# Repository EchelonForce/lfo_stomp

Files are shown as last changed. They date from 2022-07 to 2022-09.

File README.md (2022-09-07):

# Eurorack LFO Stomp

This is a PCB for a eurorack LFO based on the STOMPLFO chip from Electric Druid.

Full writeup here: https://www.robotdialogs.com/2022/09/eurorack-lfo-module-stomp-lfo.html

This work is licensed under a Creative Commons Attribution-NonCommercial-ShareAlike 4.0 International License. https://creativecommons.org/licenses/by-nc-sa/4.0/

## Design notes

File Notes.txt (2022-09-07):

Stomp-LFO Design Notes

Data sheet has a simple filter to smooth out the PDM output to make the actual LFO output. That seems okay on the breadboard. 

Initially on the breadboard I had the 7805 regulator backwards so it got super hot and let somekind of bad voltage through to the STOMPLFO, so that chip misbehaved after I corrected the regulator. It was drawing 80mA at 5V and I couldn't figure out why and the data sheet doesn't list a typical current. Since it was sort of working I started measuring the output, but was only getting 0 to ~2.5V at the output PDM pin. At this point I decided to try another chip and the new one behaved as expected, so I just fried that first chip and then had to troubleshoot to figure that out.

Breadboard doesn't have an LED output, but I like having one for LFOs, so add that in v1 PCB.
There's another Op-amp available on the output buffer. Maybe make an inverted output if there's room on the panel for another jack.

https://tinyurl.com/252rokoo

v1 pcb issues
- Filter from the data sheet that I used with the output buffer/amp's R4 created a voltage divider that makes the output 0-5V instead of 0-10V. 
    - Using (R8+R5=430k and R7=30k) cranks it up to 0-10V as desired. see https://tinyurl.com/2bfdjrho
- R10 could/should be two 1k's instead of a 2k to reduce number of components.

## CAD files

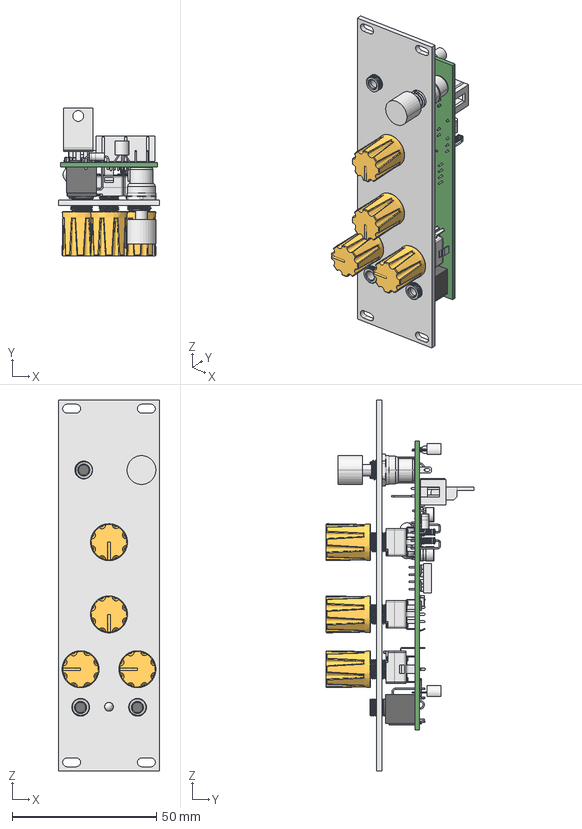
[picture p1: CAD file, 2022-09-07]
front_panel_v1/lfo_stomp_front_panel_v1.1.FCStd
35.0 x 51.3 x 128.5 mm
lfo_stomp_v1 PCB

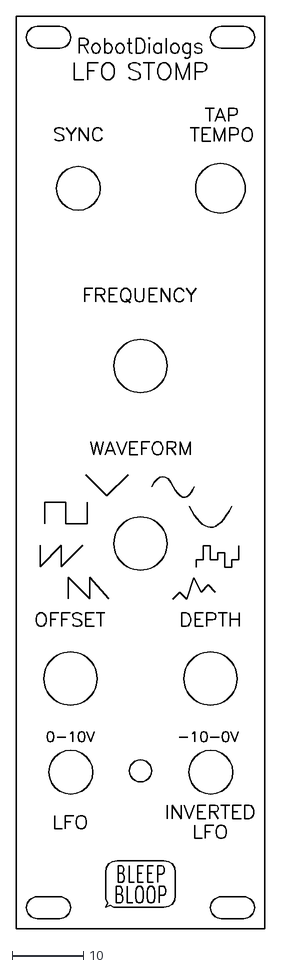
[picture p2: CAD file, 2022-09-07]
front_panel_v1/lfo_stomp_front_panel_v1.1_engraving.dxf
35.0 x 128.5

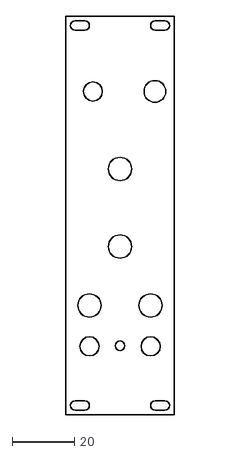
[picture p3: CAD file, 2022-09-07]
front_panel_v1/lfo_stomp_front_panel_v1_no_engraving.dxf
35.0 x 128.5

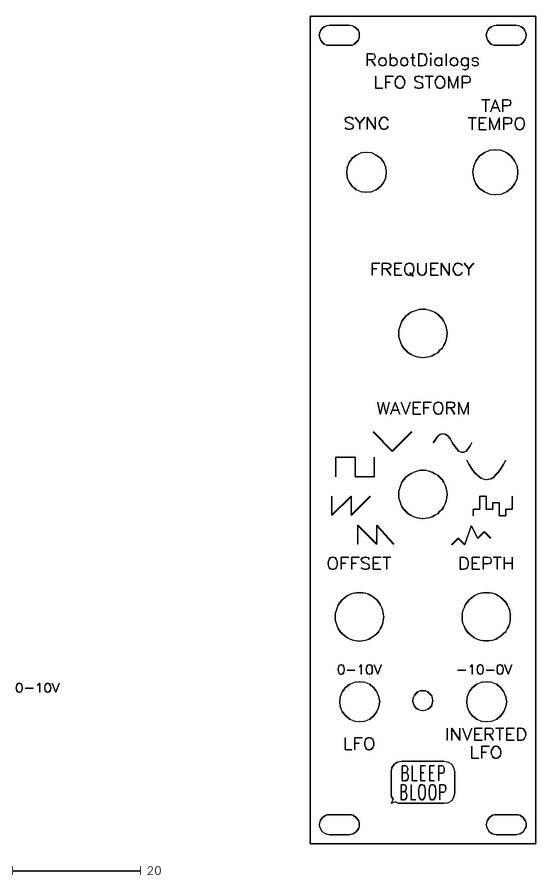
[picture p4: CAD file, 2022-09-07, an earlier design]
front_panel_v1/lfo_stomp_front_panel_v1_engraving.dxf
80.6 x 128.5

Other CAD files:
front_panel_v1/lfo_stomp_front_panel_v1.FCStd

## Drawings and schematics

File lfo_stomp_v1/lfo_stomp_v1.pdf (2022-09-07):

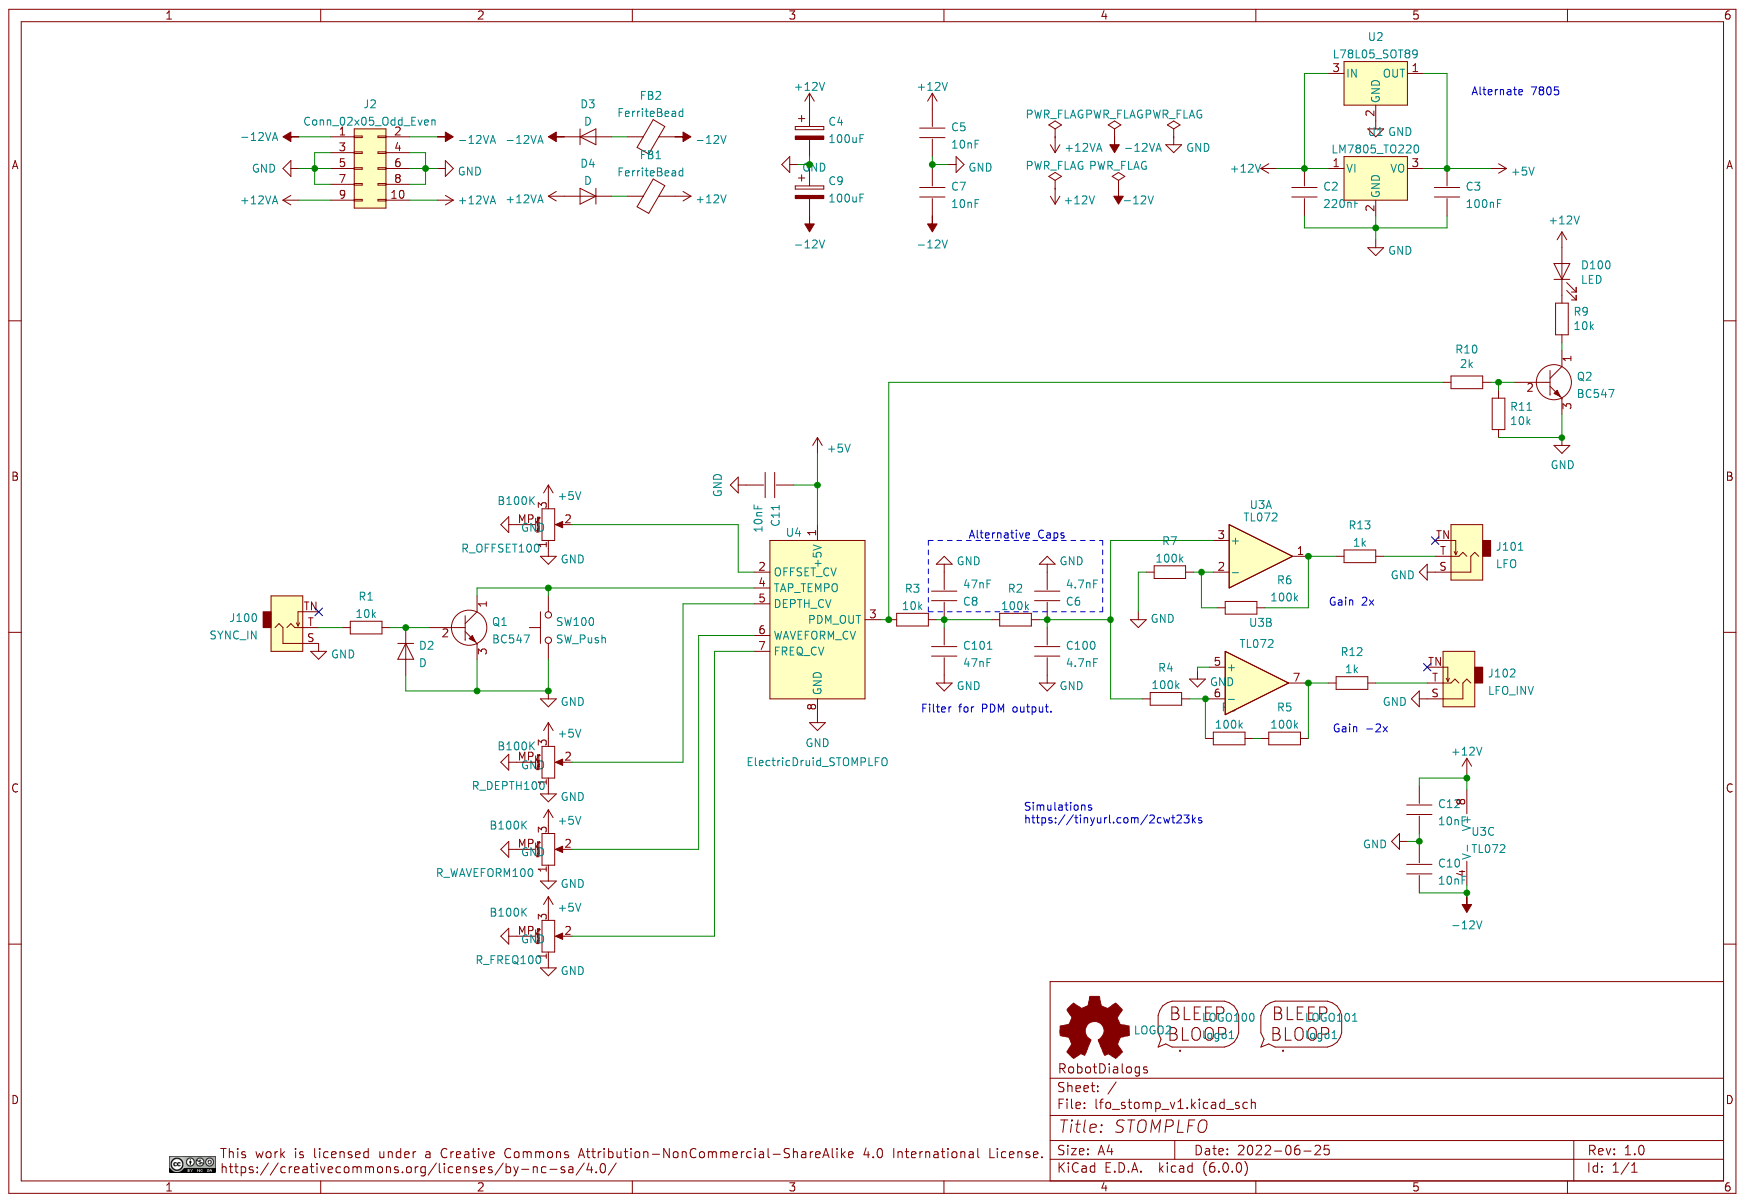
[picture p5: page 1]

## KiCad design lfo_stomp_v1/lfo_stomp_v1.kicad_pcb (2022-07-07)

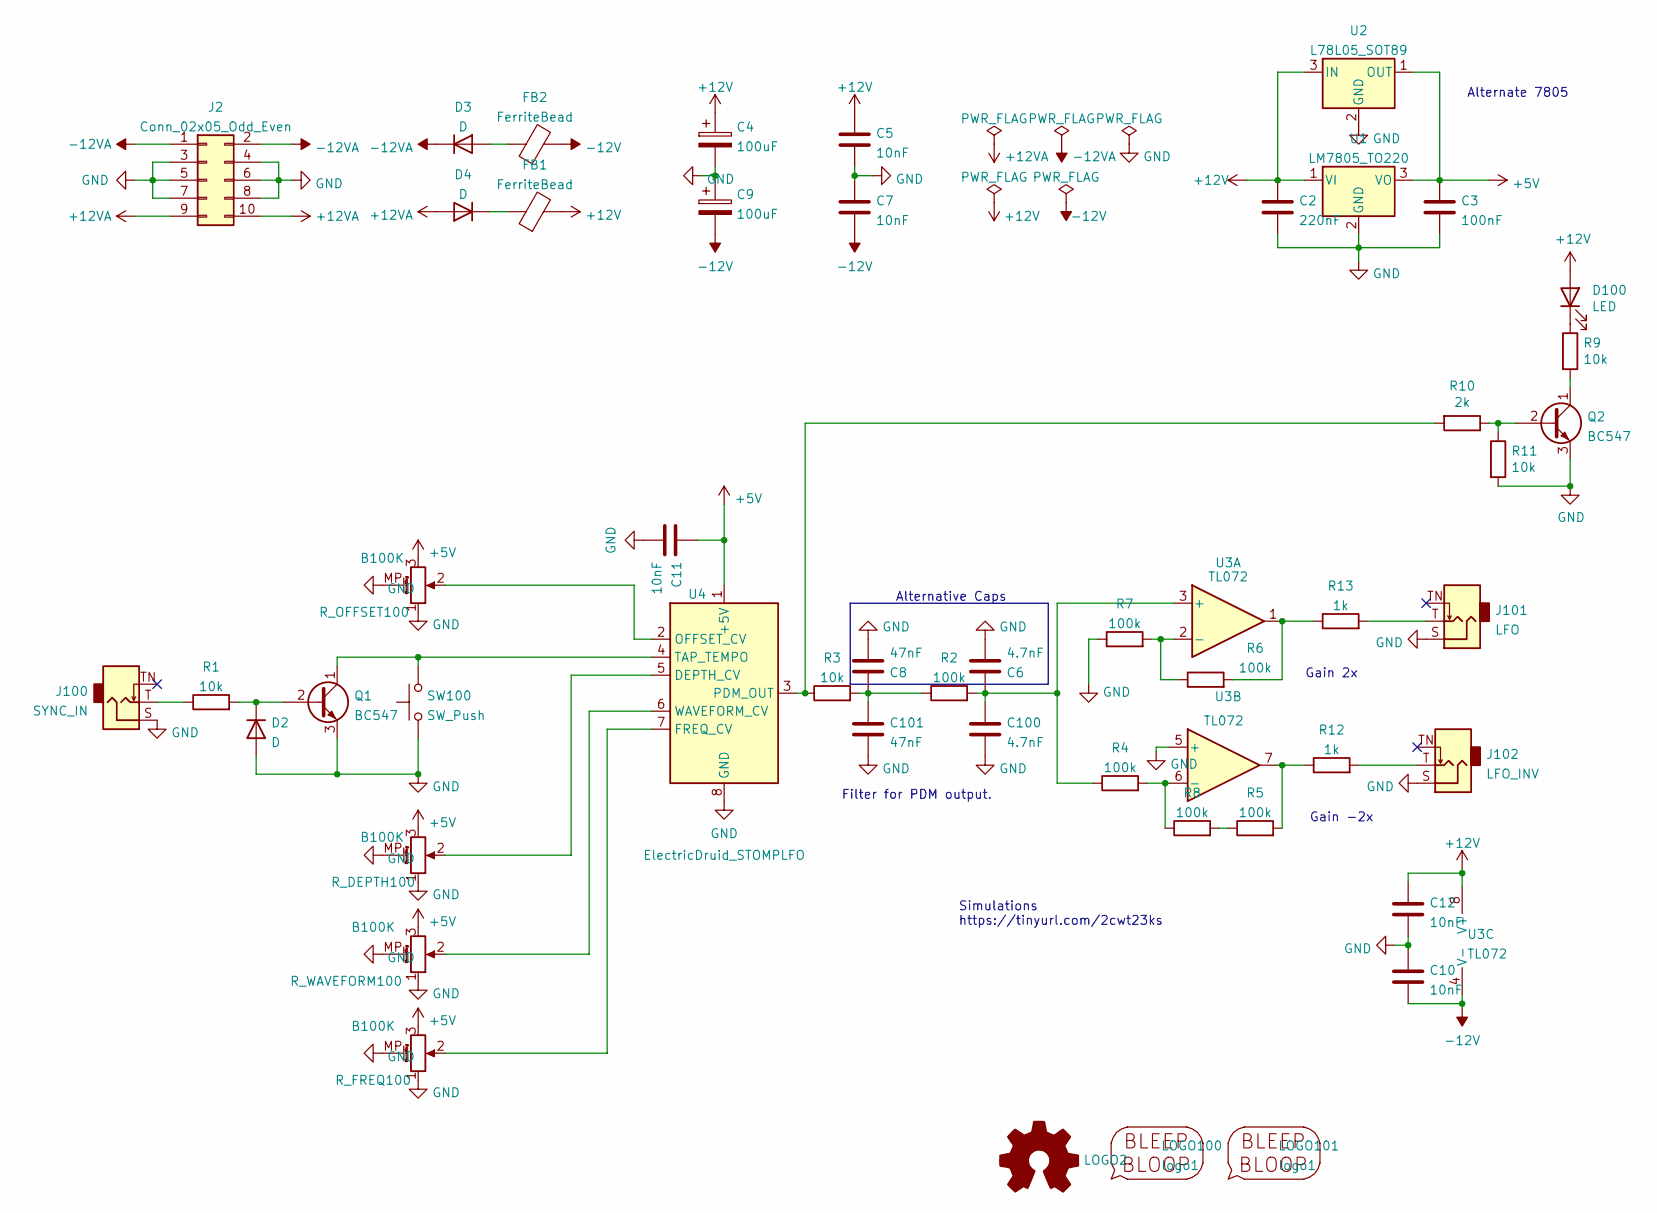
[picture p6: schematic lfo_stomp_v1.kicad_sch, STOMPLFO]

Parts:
C2: 220nF; C_1206_3216Metric_Pad1.33x1.80mm_HandSolder
C3: 100nF; C_1206_3216Metric_Pad1.33x1.80mm_HandSolder
C4, C9: 100uF; CP_Radial_D5.0mm_P2.50mm
C5, C7, C10, C11, C12: 10nF; C_1206_3216Metric_Pad1.33x1.80mm_HandSolder
C6: 4.7nF; C_1206_3216Metric_Pad1.33x1.80mm_HandSolder
C8: 47nF; C_1206_3216Metric_Pad1.33x1.80mm_HandSolder
C100: 4.7nF; C_Disc_D5.1mm_W3.2mm_P5.00mm
C101: 47nF; C_Disc_D5.1mm_W3.2mm_P5.00mm
D2, D3, D4: D; D_A-405_P7.62mm_Horizontal
D100: LED; LED_D3.0mm
FB1, FB2: FerriteBead; L_Axial_L5.3mm_D2.2mm_P2.54mm_Vertical_Vishay_IM-1
J2: Conn_02x05_Odd_Even; IDC-Header_2x05_P2.54mm_Vertical
J100: SYNC_IN; Jack_3.5mm_MJ-355W_and_PJ398SM_Vertical
J101: LFO; Jack_3.5mm_MJ-355W_and_PJ398SM_Vertical
J102: LFO_INV; Jack_3.5mm_MJ-355W_and_PJ398SM_Vertical
LOGO2: Logo_Open_Hardware_Small; OSHW-Symbol_6.7x6mm_SilkScreen
LOGO100: logo1; Logo1
LOGO101: logo1; Logo2
Q1, Q2: BC547; TO-92_Inline_Wide
R1, R3, R9, R11: 10k; R_1206_3216Metric_Pad1.30x1.75mm_HandSolder
R2, R4, R5, R6, R7, R8: 100k; R_1206_3216Metric_Pad1.30x1.75mm_HandSolder
R10: 2k; R_1206_3216Metric_Pad1.30x1.75mm_HandSolder
R12, R13: 1k; R_1206_3216Metric_Pad1.30x1.75mm_HandSolder
R_DEPTH100: B100K; Potentiometer_Alpha_RD901F-40-00D_Single_Vertical_w_3d
R_FREQ100: B100K; Potentiometer_Alpha_RD901F-40-00D_Single_Vertical_w_3d
R_OFFSET100: B100K; Potentiometer_Alpha_RD901F-40-00D_Single_Vertical_w_3d
R_WAVEFORM100: B100K; Potentiometer_Alpha_RD901F-40-00D_Single_Vertical_w_3d
SW100: SW_Push; SW_PS1024ALRED
U1: LM7805_TO220; TO-220-3_Vertical
U2: L78L05_SOT89; SOT-89-3
U3: TL072; DIP-8_W7.62mm_Socket_LongPads
U4: ElectricDruid_STOMPLFO; DIP-8_W7.62mm_Socket_LongPads

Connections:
+5V: C3.1, C11.1, R_DEPTH100.3, R_FREQ100.3, R_OFFSET100.3, R_WAVEFORM100.3, U1.3 (VO), U2.1 (OUT), U4.1 (+5V)
+12V: C2.1, C4.1, C5.1, C12.1, D100.2 (A), FB1.2, U1.1 (VI), U2.3 (IN), U3.8 (V+)
+12VA: D4.2 (A), J2.9, J2.10
-12V: C7.2, C9.2, C10.2, FB2.2, U3.4 (V-)
-12VA: D3.1 (K), J2.1, J2.2
GND: C2.2, C3.2, C4.2, C5.2, C6.2, C7.1, C8.2, C9.1, C10.1, C11.2, C12.2, C100.2, C101.2, D2.2 (A), J2.3, J2.4, J2.5, J2.6, J2.7, J2.8, J100.S, J101.S, J102.S, Q1.3 (E), Q2.3 (E), R7.1, R11.2, R_DEPTH100.1, R_DEPTH100.MP (MountPin), R_FREQ100.1, R_FREQ100.MP (MountPin), R_OFFSET100.1, R_OFFSET100.MP (MountPin), R_WAVEFORM100.1, R_WAVEFORM100.MP (MountPin), SW100.1, U1.2 (GND), U2.2 (GND), U3.5 (+), U4.8 (GND)
unnamed: C6.1, C100.1, R2.2, R4.1, U3.3 (+)
unnamed: C8.1, C101.1, R2.1, R3.2
unnamed: D2.1 (K), Q1.2 (B), R1.2
unnamed: D3.2 (A), FB2.1
unnamed: D4.1 (K), FB1.1
unnamed: D100.1 (K), R9.1
unnamed: J100.T, R1.1
unnamed: J101.T, R13.2
unnamed: J102.T, R12.2
unnamed: Q1.1 (C), SW100.2, U4.4 (TAP_TEMPO)
unnamed: R3.1, R10.2, U4.3 (PDM_OUT)
unnamed: R4.2, R8.1, U3.6 (-)
unnamed: R5.1, R8.2
unnamed: R6.1, R7.2, U3.2 (-)
unnamed: Q2.1 (C), R9.2
unnamed: Q2.2 (B), R10.1, R11.1
unnamed: R5.2, R12.1, U3.7
unnamed: R6.2, R13.1, U3.1
unnamed: R_DEPTH100.2, U4.5 (DEPTH_CV)
unnamed: R_FREQ100.2, U4.7 (FREQ_CV)
unnamed: R_OFFSET100.2, U4.2 (OFFSET_CV)
unnamed: R_WAVEFORM100.2, U4.6 (WAVEFORM_CV)

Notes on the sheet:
Filter for PDM output.
Gain 2x
Gain -2x
Simulations https://tinyurl.com/2cwt23ks
Alternate 7805
Alternative Caps

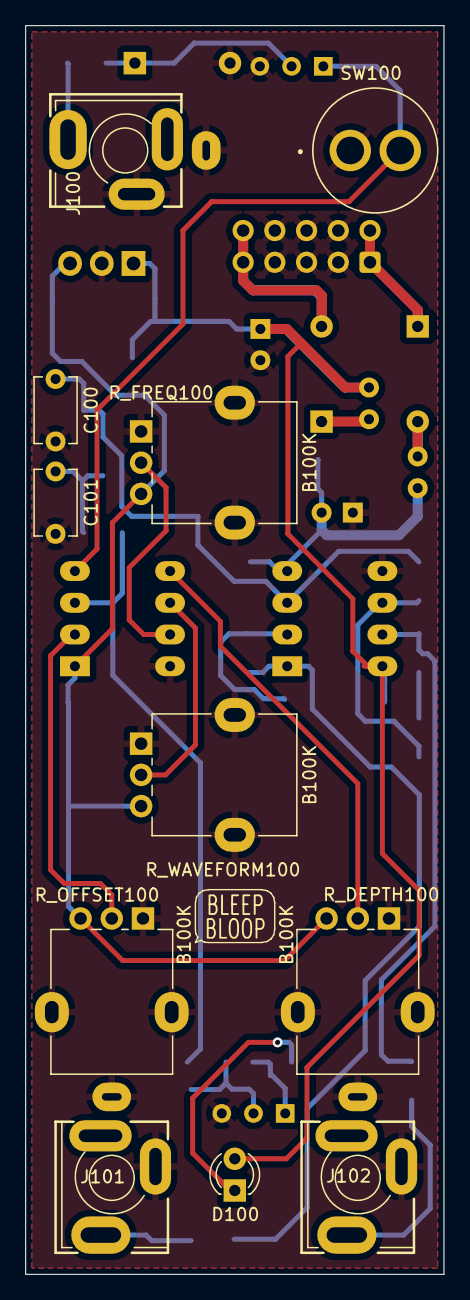
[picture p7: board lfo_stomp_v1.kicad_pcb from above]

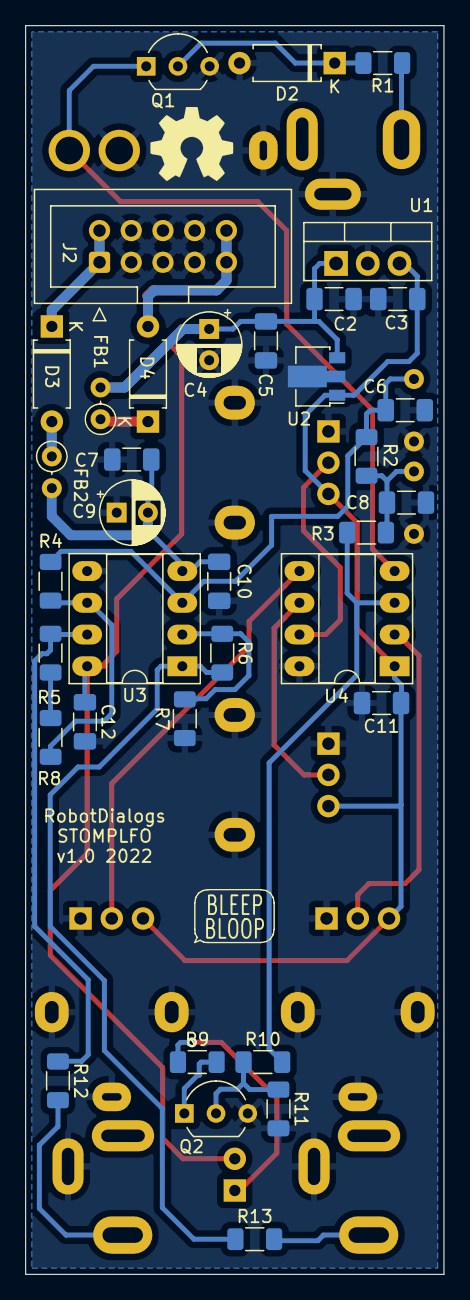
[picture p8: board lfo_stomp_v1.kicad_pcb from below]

Board: 2 copper layers, 33.5 x 100.0 mm, 50 parts (37 on the bottom side), 28 nets.

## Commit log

2022-06-25 v1 before renaming references
    [lfo_stomp_v1.kicad_pcb, lfo_stomp_v1.kicad_sch]
2022-06-25 Geographic reannotate
    [lfo_stomp_v1.kicad_pcb, lfo_stomp_v1.kicad_sch]
2022-06-25 Page titles and fixed pot orientations
    [lfo_stomp_v1.kicad_pcb, lfo_stomp_v1.kicad_sch]
2022-07-27 panelized v1
    [lfo_stomp_v1_panelized.kicad_pcb]
2022-07-27 v1 BOM and Notes.txt
2022-09-07 Front Panel v1 CAD
    [lfo_stomp_front_panel_v1.FCStd, lfo_stomp_front_panel_v1_engraving.dxf, lfo_stomp_front_panel_v1_no_engraving.dxf]
2022-09-07 Front Panel v1.1
    Moved engraving around
    [lfo_stomp_front_panel_v1.1.FCStd, lfo_stomp_front_panel_v1.1_engraving.dxf]
2022-09-07 Add schematic pdf
